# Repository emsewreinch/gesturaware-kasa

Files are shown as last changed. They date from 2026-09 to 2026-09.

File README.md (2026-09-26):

# gesturaware-kasa

GesturAware cihazinin 3D baski kasasi (OpenSCAD).

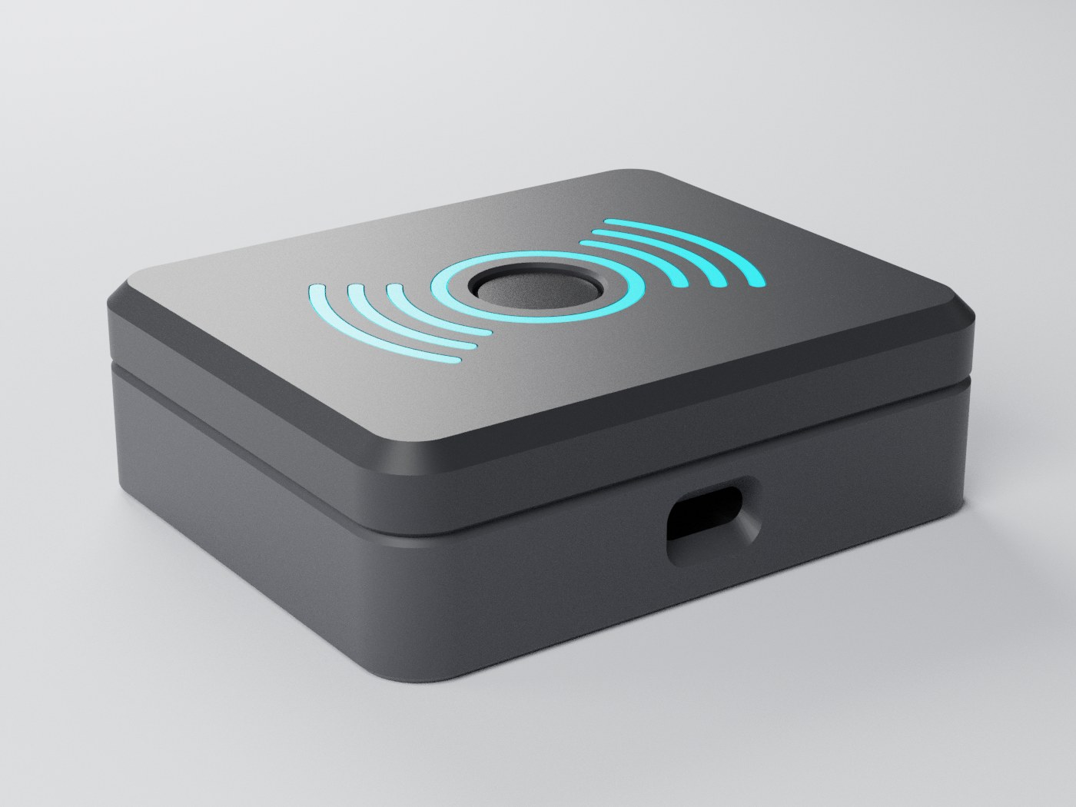
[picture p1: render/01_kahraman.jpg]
Kontrolcu surumu


## Dosyalar

- `kontrolcukasa.scad` - **kontrolcu surumu (yeni).** Oyun kontrolcusunun arkasina takilan 2 parcali kasa: kapak + govde. PCB v1 (`pcb_v1_headers_z.stl`) icin. `goster` degiskeni ile gorunum / parca secilir.
- `Cihazkasaguncel.scad` - masaustu surumu, iki parcali kasa (ust + alt), birlesik dosya. `goster` degiskeni ile gorunum secilir ("ust" / "alt" / "baski" / "acilim" / "montaj").
- `cihazkasaguncelust.scad` - masaustu ust kasa (tek parca, baski icin)
- `cihazkasaguncelalt.scad` - masaustu alt kapak (tek parca, baski icin)
- `cihaz_kasasi.scad`, `yenikasaa_ust.scad`, `yenikasaa_alt.scad` - onceki tasarim iterasyonlari
- `render/` - kontrolcu surumunun gorselleri

## Kontrolcu surumu (`kontrolcukasa.scad`)

Dis olculer degismedi: **64.74 x 53.5 x 20.6 mm**. Ic yapi PCB v1'e gore:
kart 45 x 40 x 1.6 mm, M2 delikler 39 x 34 mm aralikla, en yuksek komponent karttan 6.6 mm.
PCB, USB-C one bakacak sekilde 90 derece donuk durur; USB-C acikligi X = -0.4'te,
konnektorun kendi yuksekliginden hesaplanir (Z = 5.55 .. 8.95).

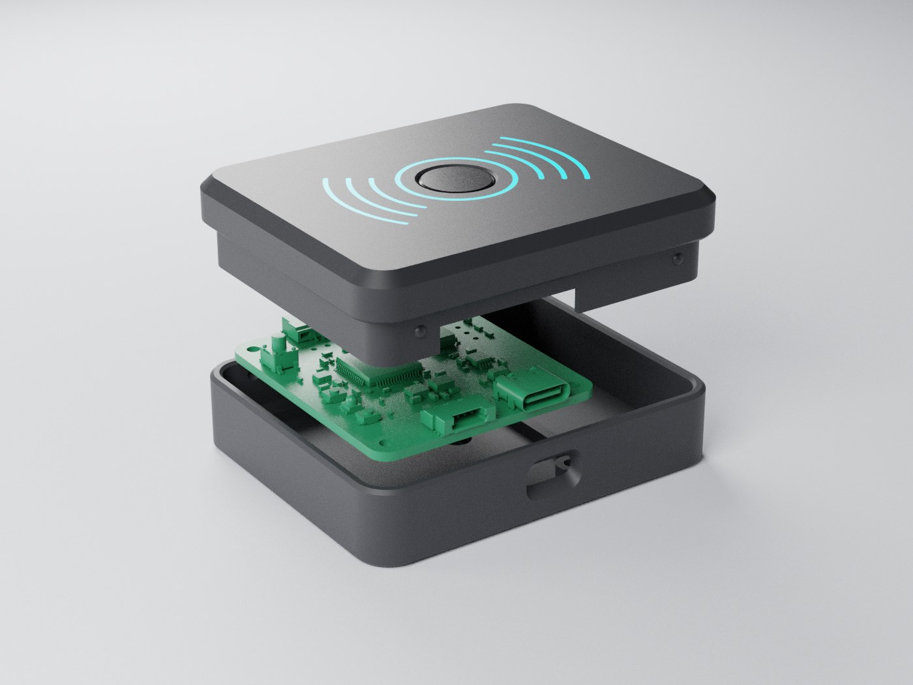
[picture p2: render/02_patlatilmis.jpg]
Parcalar


### Tasarim

- Duz ust yuzey, 45 derece pahli ust kenar (isikta keskin bir cizgi verir)
- Buton cevresinde hale halkasi ve iki yanda "(( o ))" jest dalgalari: 1.6 mm genis, 1.2 mm derin oyuk + renkli dolgu
- Kapak / govde birlesiminde 0.6 mm V-golge cizgisi; USB-C ve LED tamamen govdede, birlesim cizgisi portlari kesmiyor
- Plan kose radiusu 8 -> 6 mm: daha "tech" gorunum

| Ust yuzey | Beyaz kapak secenegi |
|---|---|
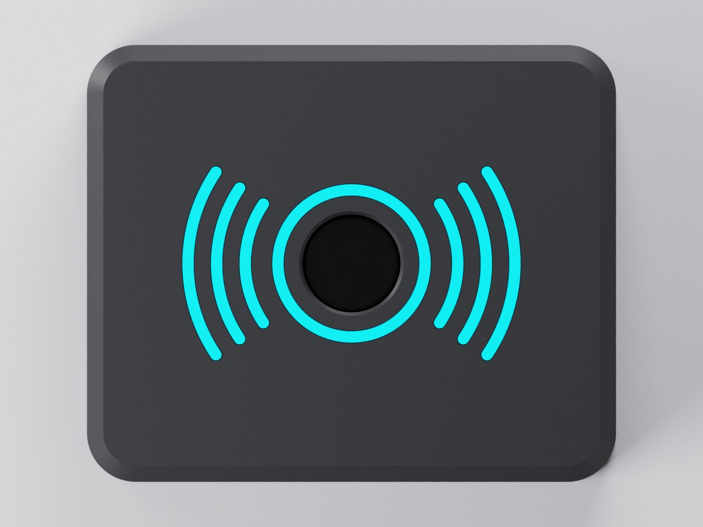
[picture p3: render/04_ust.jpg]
Ust
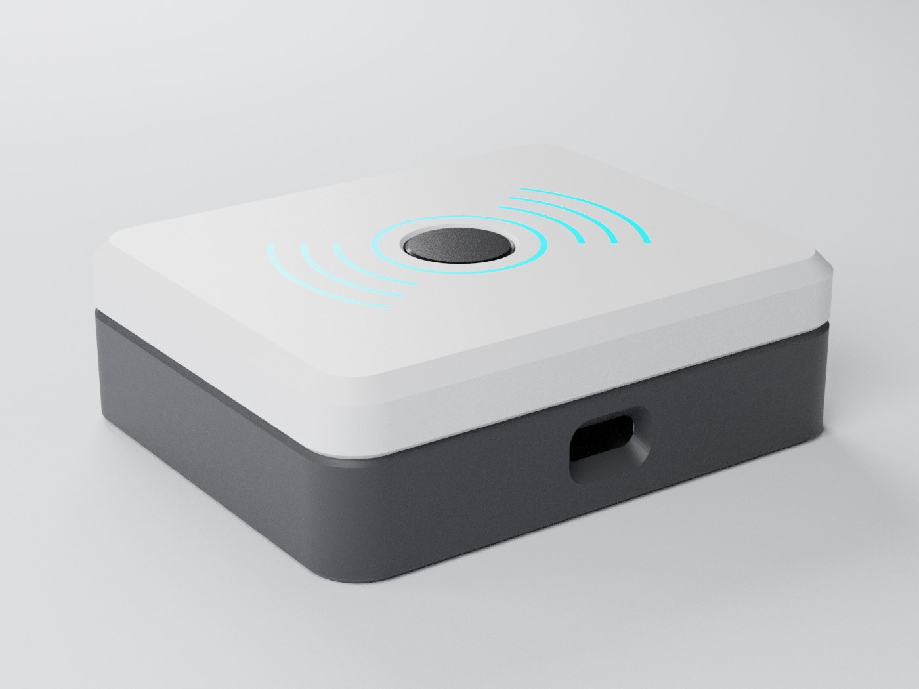
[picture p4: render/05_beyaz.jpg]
Beyaz
|  |  |

### Ic yapi ve PCB montaji

- PCB, delikleri altindaki 4 ayaga (2 mm) ve kenar rafina oturur.
- Tabanda PCB deliklerinin tam hizasinda havsali M2 delikler var: M2x8 havsa bas vida alttan,
  somun PCB ustunde. Vida basi taban yuzeyiyle ayni hizada kalir.
- Kapagin ic dudagi govdeye girer: 4 snap topu ile kilitlenir, 4 kucuk tirnakla PCB'yi
  yukaridan bastirir. Dudagin on tarafinda PCB'nin on kenarindan tasan USB-C ve konnektor icin centik var.
- PCB v1 modeli ile kontrol edildi: duvar, dudak ve tirnaklarla cakisma yok, ic duvara en az 0.47 mm pay.

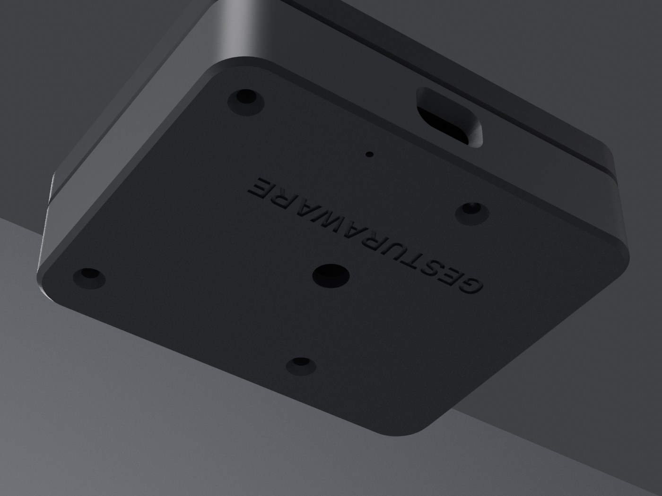
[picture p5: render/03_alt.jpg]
Alttan


### Baski (iki parca da desteksiz)

| Parca | STL icin `goster` | Tablaya gelen yuz | Not |
|---|---|---|---|
| Kapak | `kapak_baski` | ust yuzey | Dokulu PEI tabla premium mat doku verir |
| Govde | `govde_baski` | taban | |
| Dolgu | `inlay_baski` | duz | Vurgu renginde, oyuklara bastirilir |

```
openscad -D 'goster="kapak_baski"' -o kapak.stl kontrolcukasa.scad
openscad -D 'goster="govde_baski"' -o govde.stl kontrolcukasa.scad
openscad -D 'goster="inlay_baski"' -o inlay.stl kontrolcukasa.scad
```

**Renkli dolgu (inlay):** ust yuzeydeki halka ve dalgalar 1.6 mm genis, 1.2 mm derin oyuk (tavan 2.6 mm, oyuk altinda 1.4 mm kalir).
Renkli dolgu parcalari (`inlay_baski`, 7 parca) ayri basilir ve oyuklara bastirilir: her kenardan
0.14 mm kucuk (`inlay_bosluk`, 0.12 - 0.16 arasi ayarlanabilir): 1.32 mm genis (0.4 nozulla 3 cizgi), 1.2 mm yuksek.
Gerekirse bir damla yapistiriciyla sabitle.

### Montaj sirasi

1. PCB'yi govdeye yerlestir (USB-C one), 4 M2x8 havsa bas vidayi alttan tak, somunlari PCB ustunden sik.
2. LED'i arka duvardaki 5 mm delige icten tak.
3. Kapagi bastir: dudak govdeye girer, snap'ler klik yapar.

### Ayarlar

| Degisken | Varsayilan | Ne yapar |
|---|---|---|
| `usb_cx`, `pcb_cy` | -0.4, -0.7 | PCB konumu (USB-C acikligi ve vida delikleri birlikte kayar) |
| `vida_d`, `havsa_d` | 2.4, 4.4 | M2 gecis deligi ve havsa capi |
| `snap_int` | 0.4 | Kapak kilit sertligi |
| `tirnak_x` | montaj delikleri yani | PCB bastirma tirnaklari; gerekirse `tirnak_on = false` |
| `inlay_bosluk` | 0.14 | Dolgu parcasi her kenardan bu kadar kucuk |
| `oyma_on`, `yazi_on` | true | Ust desen / alt yazi |
| `pcb_goster` | false | Montaj gorunumlerinde PCB hayaleti |

## Masaustu surumu (`Cihazkasaguncel.scad`)

- Apple / minimalist tarz, duz ust yuzey
- Ortada 12 mm buton deligi
- On (-Y) duvarda USB-C acikligi (merkeze gore 1 mm saga kaydirilmis)
- Vidasiz snap kenetlenme: alt kapak lip'i uzerinde detent toplari, ust kasa ic duvarinda eslesen yuvalar. Sikilik `snap_int` ile ayarlanir.

## Kullanim

OpenSCAD ile ac, F5 onizleme / F6 render, sonra STL disa aktar (F7).

Dis olculer: ~64.7 x 53.5 x 20.6 mm.

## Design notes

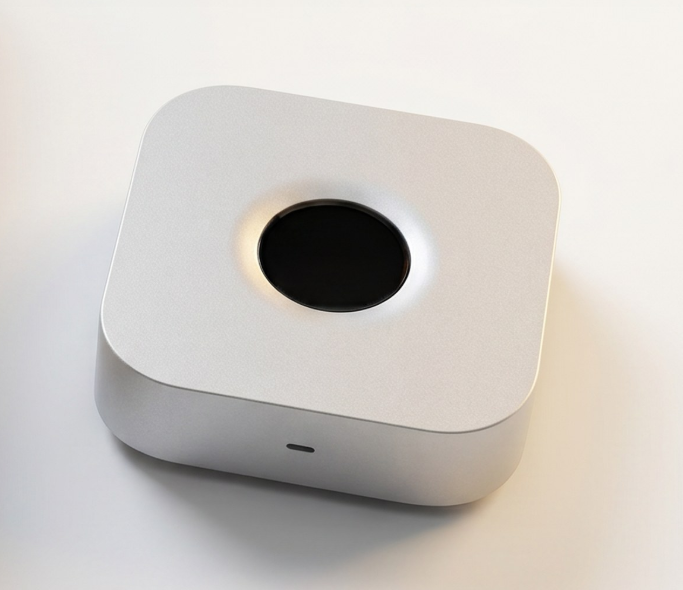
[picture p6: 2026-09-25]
Ekran görüntüsü 2026-09-13 182629.png

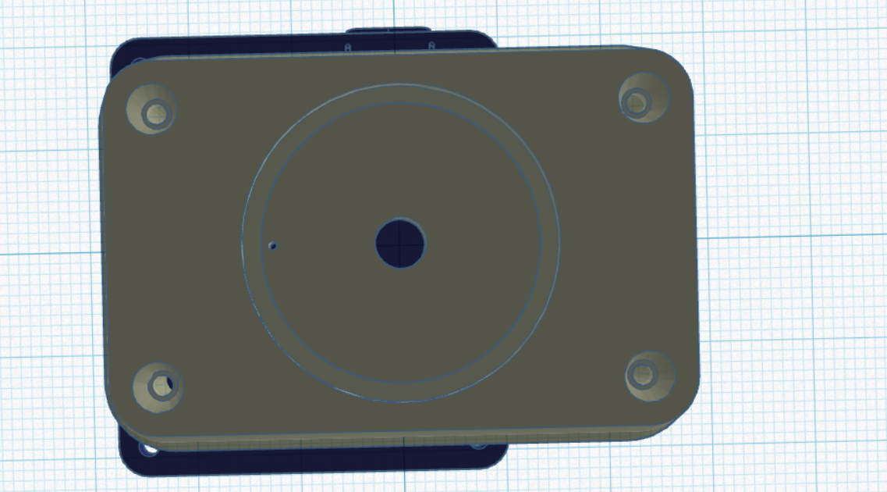
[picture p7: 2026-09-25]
yenikasaproblem1.png

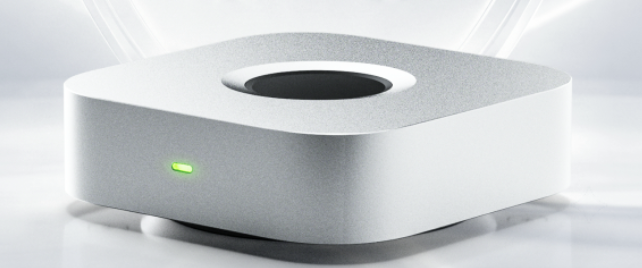
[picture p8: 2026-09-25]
Ekran görüntüsü 2026-09-13 183102.png

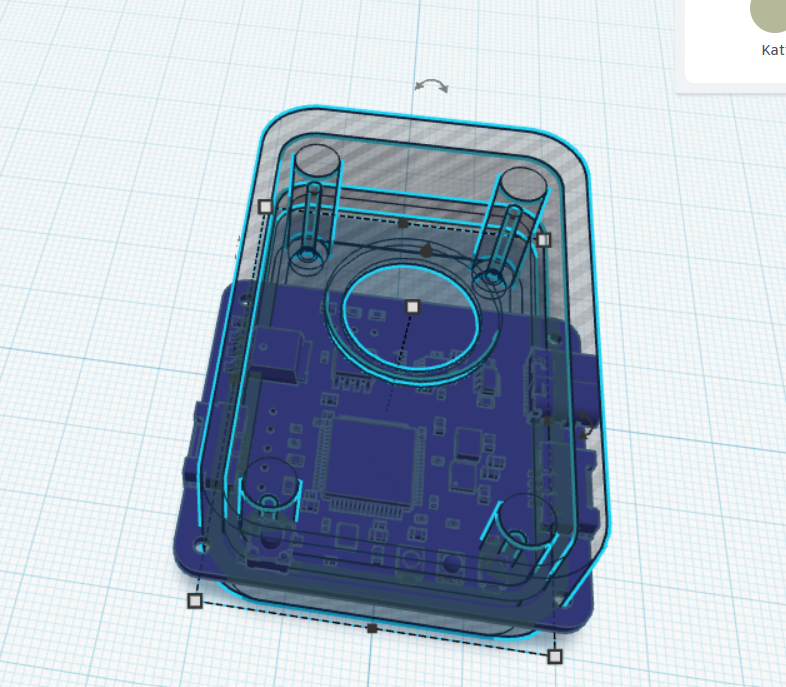
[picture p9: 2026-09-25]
yenikasaproblem2.png

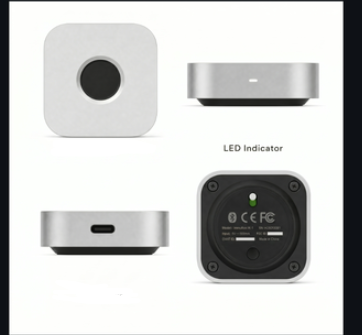
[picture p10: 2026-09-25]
Ekran görüntüsü 2026-09-13 184225.png

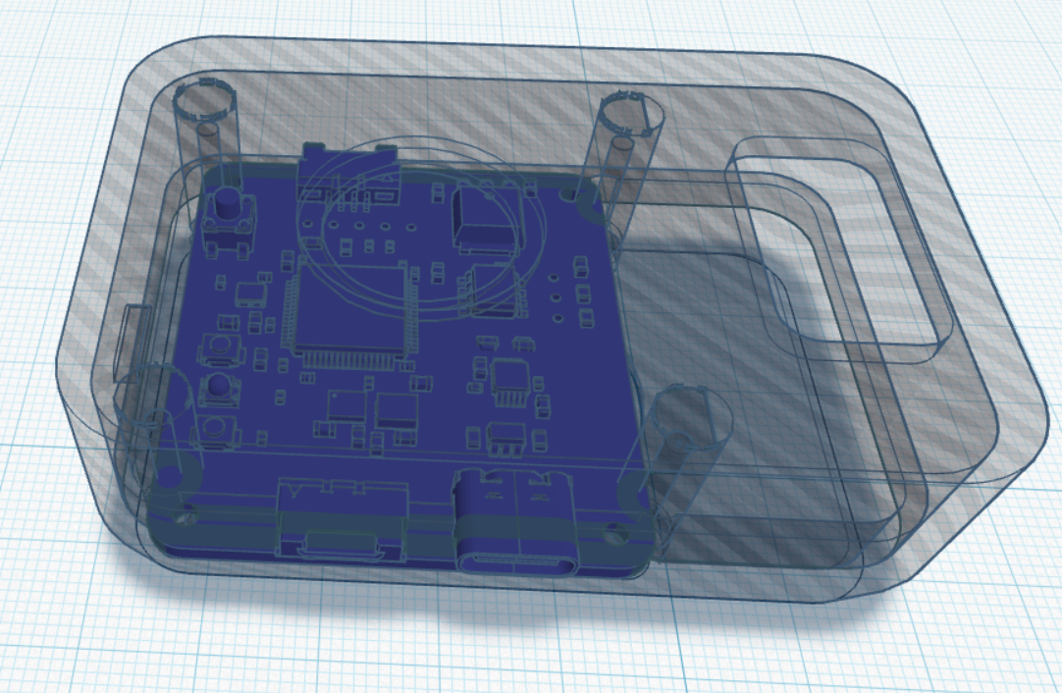
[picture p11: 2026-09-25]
yenikasaistek.png

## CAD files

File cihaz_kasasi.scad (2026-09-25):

// =============================================================
//  Cihaz Kasasi - iki parcali (ust kasa + alt kapak)  v4
//  Apple/minimalist. USB-C UZUN (on) duvarda TAM ORTADA.
//
//  Yerlesim (ustten):
//    [ PCB (EN SOLDA) ] [ gap ] [ LED (sagda) ]
//  Kart, USB kenari one bakacak sekilde; kart SOLA dayanir,
//  konnektor tam kasa merkezine gelir -> USB acikligi ortada,
//  gercek konnektorle HIZALI. Sag tarafta LED icin bosluk kalir.
//
//  KRITIK: usb_edge_off = konnektorun kart on-kenari merkezinden
//  ic tarafa (saga) kacikligi. kapaklar.scad'den 8.62 alindi.
//  Gercek kartta farkliysa TEK burayi degistir; kasa kendini ayarlar.
//
//  Tum olculer mm. z=0 tabanin en alti.
// =============================================================

$fn = 100;

/* ============================================================
   =  BILESENLER (olculen)                                     =
   ============================================================ */
pcb_edge_usb = 40.5;   // kartin USB kenari boyu -> kasa X
pcb_depth    = 46.5;   // kartin diger boyutu    -> kasa Y (en/derinlik)
pcb_thick    = 1.6;
pcb_comp_h   = 10;     // kart ustu en yuksek komponent payi
hole_ax      = 17;     // montaj deligi yari-araligi (kasa X)
hole_ay      = 19.5;   // montaj deligi yari-araligi (kasa Y)

usb_edge_off = 8.62;   // <-- konnektor, kart on-kenari merkezinden saga kacik (kapaklar.scad)
usb_w        = 9.2;    // Type-C acikligi X (uzun duvar boyunca)
usb_h        = 3.4;    // Type-C acikligi Z (yukseklik)
usb_dz       = 1.2;    // konnektor merkezinin kart USTUNDEN yuksekligi

led_ekle     = true;   // sagdaki bosluga LED modulu (hayalet + yer)
led_X        = 15;
led_Y        = 25;
led_h        = 16;

/* ============================================================
   =  YERLESIM / BOSLUKLAR                                     =
   ============================================================ */
side_clr   = 1.5;
comp_gap   = 2.0;
head_gap   = 3.0;
floor_gap  = 2.0;

/* ============================================================
   =  ESTETIK / KASA                                           =
   ============================================================ */
et            = 2;
kose_r        = 8;
taban_yuks    = 7;
lip_yuks      = 4;
lip_bosluk    = 0.3;
lip_et        = 1.5;
chamfer_inset = 2.5;

buton_cap     = 16;    // ustteki basilabilir buton deligi
havuz_cap     = 20;
havuz_derin   = 1.2;
buton_x       = 0;     // buton konumu: 0 = UST YUZEYIN TAM ORTASI (X=0 halen PCB uzerinde)
buton_y       = 0;

sutun_cap     = 5.5;
boss_cap      = 6.0;
vida_ic_cap   = 2.2;
pilot_derin   = 12;
kapak_delik   = 2.8;
havsa_ust_cap = 5.0;
havsa_derin   = 2.2;

sensor_cap    = 5.0;
reset_cap     = 1.0;
lastik_r_dis  = 15;
lastik_r_ic   = 13;
lastik_derin  = 1.0;

/* ============================================================
   =  TURETILEN OLCULER + KONUMLAR                             =
   ============================================================ */
usb_cx = 0;                 // USB acikligi tam ortada
bd_cx  = -usb_edge_off;     // kart merkezi -> konnektor X=0'a gelsin (kart sola kayar)
bd_cy  = 0;

board_l = bd_cx - pcb_edge_usb/2;   // kart sol kenari (en solda)
board_r = bd_cx + pcb_edge_usb/2;   // kart sag kenari

led_l  = board_r + comp_gap;        // LED sag bosluga
led_cx = led_l + led_X/2;
led_r  = led_l + led_X;

// Kabuk X=0 etrafinda SIMETRIK -> USB tam ortada, sol bosluk yok
right_ext = led_ekle ? max(board_r, led_r) : board_r;
half_in   = max(-board_l, right_ext) + side_clr;   // ic kavite yari-X
uzunluk   = 2*(half_in + et);                      // X (dis)

inner_y  = pcb_depth + 2*side_clr;
genislik = inner_y + 2*et;                          // Y (dis)
inner_h  = max(led_h, floor_gap + pcb_thick + pcb_comp_h) + head_gap;
toplam_yuks = inner_h + 2*et;

z_floor_top = et;
z_rest      = z_floor_top + floor_gap;
z_pcb_top   = z_rest + pcb_thick;
tavan_z     = toplam_yuks - et;
seam_z      = taban_yuks;
usb_cz      = z_pcb_top + usb_dz;

cc = 0;   // kabuk merkezi (simetrik)

hole_positions = [ for (sx=[-1,1], sy=[-1,1]) [bd_cx + sx*hole_ax, sy*hole_ay] ];

/* =============================================================
                     YARDIMCI MODULLER
   ============================================================= */
module rrect(l, w, r) {
    rr = max(min(r, l/2, w/2), 0.1);
    hull() for (sx = [-1, 1], sy = [-1, 1])
        translate([sx*(l/2 - rr), sy*(w/2 - rr)]) circle(r = rr);
}
module rbox(l, w, h, r) { linear_extrude(height = h) rrect(l, w, r); }

/* =============================================================
                        UST KASA
   ============================================================= */
module ust_kasa() {
    union() {
        difference() {
            translate([cc, 0, seam_z])
                rbox(uzunluk, genislik, toplam_yuks - seam_z, kose_r);
            translate([cc, 0, seam_z - 1])
                rbox(uzunluk - 2*et, genislik - 2*et,
                     tavan_z - (seam_z - 1), kose_r - et);
            buton_bosluk();     // PCB merkezi uzerinde
            usb_bosluk();       // on (-Y) uzun duvar, tam ortada
        }
        ust_standoffs();
    }
}

module buton_bosluk() {
    translate([buton_x, buton_y, toplam_yuks - havuz_derin])
        cylinder(h = havuz_derin + 0.1, d = havuz_cap);
    translate([buton_x, buton_y, tavan_z - 0.1])
        cylinder(h = et + 0.2, d = buton_cap);
}

// USB kesimi: -Y (on) duvarda, X=usb_cx (orta), stadyum slot
module usb_bosluk() {
    r = usb_h / 2;
    translate([usb_cx, -genislik/2, usb_cz])
        hull()
            for (dx = [-(usb_w/2 - r), (usb_w/2 - r)])
                translate([dx, 0, 0])
                    rotate([90, 0, 0])
                        cylinder(h = et + 4, r = r, center = true, $fn = 48);
}

module ust_standoffs() {
    for (p = hole_positions)
        translate([p[0], p[1], z_pcb_top])
            difference() {
                cylinder(h = tavan_z - z_pcb_top, d = sutun_cap);
                translate([0, 0, -0.1]) cylinder(h = pilot_derin, d = vida_ic_cap);
            }
}

/* =============================================================
                        ALT KAPAK
   ============================================================= */
module alt_kapak() {
    difference() {
        union() {
            difference() { etek_solid(); skirt_ic(); }
            lip();
            alt_bosslar();
        }
        kapak_vida_delikleri();
        usb_bosluk();   // USB seam'i asar -> alt kabukta da acilir
        translate([cc, 0, -1]) cylinder(h = et + 2, d = sensor_cap);
        translate([bd_cx, -hole_ay - 2, -1]) cylinder(h = et + 2, d = reset_cap);
        lastik_olugu();
    }
}

module etek_solid() {
    translate([cc, 0, 0]) hull() {
        linear_extrude(height = 0.1)
            rrect(uzunluk - 2*chamfer_inset, genislik - 2*chamfer_inset,
                  kose_r - chamfer_inset);
        translate([0, 0, seam_z - 0.1])
            linear_extrude(height = 0.1) rrect(uzunluk, genislik, kose_r);
    }
}
module skirt_ic() {
    translate([cc, 0, 0]) hull() {
        translate([0, 0, et]) linear_extrude(height = 0.1)
            rrect(uzunluk - 2*chamfer_inset - 2*et,
                  genislik - 2*chamfer_inset - 2*et,
                  max(kose_r - chamfer_inset - et, 0.5));
        translate([0, 0, seam_z]) linear_extrude(height = 0.1)
            rrect(uzunluk - 2*et, genislik - 2*et, kose_r - et);
    }
}
module lip() {
    translate([cc, 0, et]) linear_extrude(height = (seam_z - et) + lip_yuks)
        difference() {
            rrect(uzunluk - 2*et - 2*lip_bosluk, genislik - 2*et - 2*lip_bosluk,
                  kose_r - et - lip_bosluk);
            rrect(uzunluk - 2*et - 2*lip_bosluk - 2*lip_et,
                  genislik - 2*et - 2*lip_bosluk - 2*lip_et,
                  max(kose_r - et - lip_bosluk - lip_et, 0.5));
        }
}
module alt_bosslar() {
    for (p = hole_positions)
        translate([p[0], p[1], et]) cylinder(h = z_rest - et, d = boss_cap);
}
module kapak_vida_delikleri() {
    for (p = hole_positions)
        translate([p[0], p[1], 0]) {
            translate([0, 0, -0.1]) cylinder(h = z_rest + 1, d = kapak_delik);
            translate([0, 0, -0.1])
                cylinder(h = havsa_derin + 0.1, d1 = havsa_ust_cap, d2 = kapak_delik);
        }
}
module lastik_olugu() {
    translate([cc, 0, -0.01]) linear_extrude(height = lastik_derin + 0.01)
        difference() { circle(r = lastik_r_dis); circle(r = lastik_r_ic); }
}
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

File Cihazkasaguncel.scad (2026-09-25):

// =============================================================
// Cihaz Kasasi - iki parcali
// Ust kasa + alt kapak
// Apple / minimalist
// USB-C on (-Y) duvarda TAM ORTADA
//
// Tum olculer mm.
// Z=0 tabanin en alti.
// =============================================================

$fn = 100;


// =============================================================
// BILESEN / PCB OLCULERI
// =============================================================

pcb_edge_usb = 40.5;       // PCB X boyu
pcb_depth    = 46.5;       // PCB Y boyu
pcb_thick    = 1.6;

pcb_comp_h   = 10;         // PCB ustu maksimum komponent yuksekligi

hole_ax = 17;              // Vida delikleri X yari-araligi
hole_ay = 19.5;            // Vida delikleri Y yari-araligi

// USB konnektorunun PCB on kenarindan iceri kacikligi
usb_edge_off = 8.62;

usb_w     = 9.2;           // USB-C acikligi X (evrensel ~9.0-9.2mm)
usb_bos_h = 3.4;           // USB-C acikligi Z (evrensel ~3.2-3.4mm)
usb_alt   = 4;             // acikligin alt kenari tabandan yukseklik (4mm)
usb_r     = 1.7;           // kose yuvarlatma (uclar tam yuvarlak = kapsul)

// On agiz: kablonun GOVDESI (apple type-c) de rahatca otursun diye on yuzde flare
usb_agiz_w     = 10.5;     // on agiz genisligi (apple kablo govde genisligi gibi)
usb_agiz_h     = 7.0;      // on agiz yuksekligi
usb_agiz_r     = 2.5;      // on agiz kose yuvarlatma
usb_agiz_derin = 2;        // flare derinligi (et=2 => tum on katman chamfer)


// =============================================================
// YERLESIM / BOSLUKLAR
// =============================================================

side_clr  = 1.5;           // PCB-kasa yan boslugu
head_gap  = 3.0;           // PCB ustu bosluk
floor_gap = 2.0;           // PCB alt boslugu


// =============================================================
// KASA AYARLARI
// =============================================================

et = 2;                    // Duvar kalinligi

kose_r = 8;                // Dis koselerin radiusu

taban_yuks = 7;            // Alt kapak / seam yuksekligi

lip_yuks  = 4;
lip_bosluk = 0.3;
lip_et = 1.5;

chamfer_inset = 2.5;


// =============================================================
// SNAP - VIDASIZ KENETLENME
// Lip uzerindeki detent toplari, ust kasadaki yuvalara oturur.
// =============================================================

snap_on       = true;   // snap kenetlenme acik/kapali
snap_x_off    = 20;     // snap'lerin merkezden X uzakligi (USB'yi es gecer)
snap_d        = 2.4;    // lip uzerindeki detent topu capi
snap_pocket_d = 2.9;    // ust duvardaki yuva capi (bumptan buyuk)
snap_int      = 0.4;    // sikilik / interferans (mm) - artir = daha sert klik


// =============================================================
// UST BUTON
// =============================================================

buton_cap = 12;
havuz_cap = 20;
havuz_derin = 1.2;

buton_x = 0;
buton_y = 0;

// Ust tumsek (buton meme-ucu gibi durmasin diye)
tepe_h     = 3.5;          // buton cevresi tumsek merkez yuksekligi (duz uste gore)
tepe_r     = 22;           // bu yaricapta duz uste tegetlenir (tumsek yaricapi)
tepe_steps = 48;           // profil cozunurlugu


// =============================================================
// VIDA / MONTAJ
// =============================================================

sutun_cap = 5.5;
boss_cap = 6.0;

vida_ic_cap = 2.2;
pilot_derin = 12;

kapak_delik = 2.8;

havsa_ust_cap = 5.0;
havsa_derin = 2.2;


// =============================================================
// ALT SENSOR / RESET DELIKLERI
// =============================================================

sensor_cap = 5.0;
reset_cap = 1.0;


// =============================================================
// ALT KAPAK LASTIK OLGUSU
// =============================================================

lastik_r_dis = 15;
lastik_r_ic = 13;
lastik_derin = 1.0;


// =============================================================
// ARKA SEFFAF NOKTA (tek-katman isik gecisi)
// =============================================================

nokta_cap   = 1.0;         // nokta capi
nokta_kalan = 0.4;         // ic yuzeyde kalan et (~2 katman; 0.2 = tek katman)
nokta_x     = 0;           // arka (+Y) duvarda X konumu


// =============================================================
// ARKA LED DELIGI (5mm LED - arka +Y duvar, sag)
// =============================================================

led_cap = 5.0;             // 5mm LED icin delik capi
led_x   = 18;              // +X (sag) konum
led_z   = 10;              // yukseklik (tabandan)


// =============================================================
// TURETILEN OLCULER
// =============================================================

// USB-C merkeze gore 1 mm saga (+X) kaydirildi
usb_cx = 1;

// PCB, USB konnektorunu kasa merkezine getirmek icin sola kayiyor
bd_cx = -usb_edge_off;

bd_cy = 0;


// PCB X sinirlari
board_l = bd_cx - pcb_edge_usb / 2;
board_r = bd_cx + pcb_edge_usb / 2;


// PCB'nin en dis noktasi + bosluk
right_ext = board_r;

half_in = max(-board_l, right_ext) + side_clr;


// =============================================================
// KASA DIS X BOYUTU
// =============================================================

uzunluk = 2 * (half_in + et);


// =============================================================
// KASA DIS Y BOYUTU
// =============================================================

inner_y = pcb_depth + 2 * side_clr;

genislik = inner_y + 2 * et;


// =============================================================
// KASA Z BOYUTU
// =============================================================

inner_h =
    floor_gap
    + pcb_thick
    + pcb_comp_h
    + head_gap;

toplam_yuks = inner_h + 2 * et;


// Alt ic taban
z_floor_top = et;

// PCB alt seviyesi
z_rest = z_floor_top + floor_gap;

// PCB ust seviyesi
z_pcb_top = z_rest + pcb_thick;

// Ust tavanin ic yuzeyi
tavan_z = toplam_yuks - et;

// Ust / alt kapak birlesim seviyesi
seam_z = taban_yuks;

// Arka seffaf nokta yuksekligi (seam ile tavan arasi orta)
nokta_z = (seam_z + tavan_z) / 2;


// USB acikligi dikey sinirlari (alt kenar tabandan usb_alt, yukseklik usb_bos_h)
usb_z0 = usb_alt;
usb_z1 = usb_alt + usb_bos_h;


// Kasa merkezi
cc = 0;


// =============================================================
// VIDA DELIK POZISYONLARI
// =============================================================

hole_positions =
[
    for (sx = [-1, 1], sy = [-1, 1])
    [
        bd_cx + sx * hole_ax,
        sy * hole_ay
    ]
];


// =============================================================
// YARDIMCI MODULLER
// =============================================================

module rrect(l, w, r)
{
    rr = max(min(r, l / 2, w / 2), 0.1);

    hull()
    {
        for (sx = [-1, 1], sy = [-1, 1])
        {
            translate(
                [
                    sx * (l / 2 - rr),
                    sy * (w / 2 - rr)
                ]
            )
            circle(r = rr);
        }
    }
}


module rbox(l, w, h, r)
{
    linear_extrude(height = h)
        rrect(l, w, r);
}


// =============================================================
// UST KASA
// =============================================================

module ust_kasa()
{
    union()
    {
        difference()
        {
            // -------------------------------------------------
            // DIS KABUK + UST TUMSEK
            // -------------------------------------------------

            union()
            {
                translate(
                    [
                        cc,
                        0,
                        seam_z
                    ]
                )
                rbox(
                    uzunluk,
                    genislik,
                    toplam_yuks - seam_z,
                    kose_r
                );

                // ust_tepe();   // UST TUMSEK KALDIRILDI - duz ust istendi
            }


            // -------------------------------------------------
            // IC BOSLUK
            // -------------------------------------------------

            translate(
                [
                    cc,
                    0,
                    seam_z - 1
                ]
            )
            rbox(
                uzunluk - 2 * et,
                genislik - 2 * et,
                tavan_z - (seam_z - 1),
                kose_r - et
            );


            // -------------------------------------------------
            // UST BUTON BOSLUGU
            // -------------------------------------------------

            buton_bosluk();


            // -------------------------------------------------
            // USB-C BOSLUGU
            // -------------------------------------------------

            usb_bosluk();
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

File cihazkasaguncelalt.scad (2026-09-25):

// =============================================================
// GESTURAWARE - ALT KAPAK
// Tek parca alt kapak
// Apple / minimalist
//
// Tum olculer mm.
// Z=0 tabanin en alti
// =============================================================

$fn = 100;


// =============================================================
// PCB OLCULERI
// =============================================================

pcb_edge_usb = 40.5;
pcb_depth    = 46.5;

side_clr = 1.5;

et = 2;
kose_r = 8;

taban_yuks = 7;


// =============================================================
// USB-C
// =============================================================

usb_edge_off = 8.62;

usb_w     = 9.2;
usb_bos_h = 3.4;
usb_alt   = 4;
usb_r     = 1.7;

usb_agiz_w     = 10.5;
usb_agiz_h     = 7.0;
usb_agiz_r     = 2.5;
usb_agiz_derin = 2;


// =============================================================
// VIDA / MONTAJ
// =============================================================

hole_ax = 17;
hole_ay = 19.5;

kapak_delik = 2.8;

havsa_ust_cap = 5.0;
havsa_derin   = 2.2;


// =============================================================
// ALT DELIKLER
// =============================================================

sensor_cap = 5.0;
reset_cap  = 1.0;


// =============================================================
// ALT KAPAK LASTIK OLGUSU
// =============================================================

lastik_r_dis = 15;
lastik_r_ic  = 13;
lastik_derin = 1.0;


// =============================================================
// KASA AYARLARI
// =============================================================

lip_yuks   = 4;
lip_bosluk = 0.3;
lip_et     = 1.5;

chamfer_inset = 2.5;


// =============================================================
// SNAP - VIDASIZ KENETLENME
// Lip uzerindeki detent toplari, ust kasadaki yuvalara oturur.
// =============================================================

snap_on       = true;   // snap kenetlenme acik/kapali
snap_x_off    = 20;     // snap'lerin merkezden X uzakligi (USB'yi es gecer)
snap_d        = 2.4;    // lip uzerindeki detent topu capi
snap_pocket_d = 2.9;    // ust duvardaki yuva capi (bumptan buyuk)
snap_int      = 0.4;    // sikilik / interferans (mm) - artir = daha sert klik


// =============================================================
// TURETILEN OLCULER
// =============================================================

// PCB merkezi
bd_cx = -usb_edge_off;


// PCB X sinirlari
board_l = bd_cx - pcb_edge_usb / 2;
board_r = bd_cx + pcb_edge_usb / 2;


// PCB + yan bosluk
right_ext = board_r;

half_in = max(-board_l, right_ext) + side_clr;


// Kasa dis X
uzunluk = 2 * (half_in + et);


// Kasa dis Y
inner_y = pcb_depth + 2 * side_clr;
genislik = inner_y + 2 * et;


// Birlesim seviyesi
seam_z = taban_yuks;


// =============================================================
// VIDA POZISYONLARI
// =============================================================

hole_positions =
[
    for (sx = [-1, 1], sy = [-1, 1])
    [
        bd_cx + sx * hole_ax,
        sy * hole_ay
    ]
];


// =============================================================
// YARDIMCI MODUL
// =============================================================

module rrect(l, w, r)
{
    rr = max(min(r, l / 2, w / 2), 0.1);

    hull()
    {
        for (sx = [-1, 1], sy = [-1, 1])
        {
            translate(
                [
                    sx * (l / 2 - rr),
                    sy * (w / 2 - rr)
                ]
            )
            circle(r = rr);
        }
    }
}


// =============================================================
// ALT KAPAK
// =============================================================

module alt_kapak()
{
    difference()
    {
        union()
        {
            // Ana govde
            difference()
            {
                etek_solid();
                skirt_ic();
            }

            // Ic gecme lip'i
            lip();

            // Vidasiz snap toplari
            snap_bumps();
        }


        // -----------------------------------------------------
        // VIDA DELIKLERI
        // -----------------------------------------------------

        kapak_vida_delikleri();


        // -----------------------------------------------------
        // USB-C DELIGI
        // -----------------------------------------------------

        usb_bosluk();


        // -----------------------------------------------------
        // SENSOR DELIGI
        // -----------------------------------------------------

        translate(
            [
                0,
                0,
                -1
            ]
        )
        cylinder(
            h = et + 2,
            d = sensor_cap
        );


        // -----------------------------------------------------
        // RESET DELIGI
        // -----------------------------------------------------

        translate(
            [
                bd_cx,
                -hole_ay - 2,
                -1
            ]
        )
        cylinder(
            h = et + 2,
            d = reset_cap
        );


        // -----------------------------------------------------
        // LASTIK OLGUSU
        // -----------------------------------------------------

        lastik_olugu();
    }
}


// =============================================================
// ALT KAPAK DIS GOVDESI
// =============================================================

module etek_solid()
{
    translate([0, 0, 0])
    hull()
    {
        // Alt kisim
        linear_extrude(height = 0.1)
        rrect(
            uzunluk - 2 * chamfer_inset,
            genislik - 2 * chamfer_inset,
            kose_r - chamfer_inset
        );


        // Ust kisim
        translate(
            [
                0,
                0,
                seam_z - 0.1
            ]
        )
        linear_extrude(height = 0.1)
        rrect(
            uzunluk,
            genislik,
            kose_r
        );
    }
}


// =============================================================
// ALT KAPAK IC BOSLUGU
// =============================================================

module skirt_ic()
{
    translate([0, 0, 0])
    hull()
    {
        // Alt ic kisim
        translate(
            [
                0,
                0,
                et
            ]
        )
        linear_extrude(height = 0.1)
        rrect(
            uzunluk
                - 2 * chamfer_inset
                - 2 * et,

            genislik
                - 2 * chamfer_inset
                - 2 * et,
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

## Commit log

2026-09-25 GesturAware kasa: OpenSCAD kaynak dosyalari ve gorseller
    Duz ust yuzey, 12mm buton deligi, USB-C 1mm saga kaydirildi,
    vidasiz snap kenetlenme sistemi (lip detent + ust yuva).
    [Cihazkasaguncel.scad, cihaz_kasasi.scad, cihazkasaguncelalt.scad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]
2026-09-25 Kontrolcu surumu: kizakli premium kasa (kontrolcukasa.scad)
    - Dis olculer ayni (64.74 x 53.5 x 20.6 mm); PCB, USB-C, buton, LED,
    sensor ve reset konumlari Cihazkasaguncel.scad ile ayni
    - 3 parca (kapak, govde, kizak), hepsi desteksiz basilir
    - 45 derece ust pah, buton cevresinde hale halkasi ve "(( o ))" jest
    dalgalari (0.4 mm oyma, renkli baski / inlay destegi), V-golge cizgileri
    - Kontrolcuye VHB bantla yapisan kizak: kirlangic ray, arka durdurucu,
    esnek parmakli klik kilit, tikirti alan taban tumsekleri
    - PCB rafi ve kapak tirnaklari; dudak ile PCB kenari arasinda 0.3 mm pay
    (eski dosyada dudak PCB kenarina ~0.3 mm giriyordu)
    - README guncellendi, render gorselleri eklendi
    Co-Aut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
    [kontrolcukasa.scad]
2026-09-26 USB-C acikligini 1.4 mm sola, 0.5 mm asagi kaydir
    usb_cx 1 -> -0.4, usb_alt 4 -> 3.5. Dudak centigi ve raf boslugu
    otomatik takip ediyor; render gorselleri guncellendi.
    Claude-Session: https://claude.ai/code/session_01Cw47JAQLn6ddWJcZ3qnMbE
    [kontrolcukasa.scad]
2026-09-26 Kizagi kaldir, kasayi PCB v1'e gore guncelle
    - Kizak (dovetail ray, esnek parmaklar) ve govdedeki kizak oluklari kaldirildi;
    govde tabani her yonde pahli duz taban
    - PCB olculeri pcb_v1_headers_z.stl'den: 45 x 40 x 1.6 mm, M2 delikler
    39 x 34 mm, komponent yuksekligi 6.6 mm; dis olculer sabit
    - Tabanda PCB deliklerinin hizasinda havsali M2 delikler ve 2 mm PCB ayaklari
    - USB-C acikligi konnektorun modeldeki yuksekliginden hesaplaniyor
    - Dudak on centigi PCB on kenarindan tasan konnektorlere gore genisletildi,
    on snap'ler centik disina alindi
    - README ve render gorselleri guncellendi
    Claude-Session: https://claude.ai/code/session_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
    [kontrolcukasa.scad]
2026-09-26 Ust desen: 1.6 x 1.2 mm oyuk ve ayri basilan dolgu parcalari
    - Halka ve dalga oyuklari 0.8 -> 1.6 mm genis, 0.4 -> 1.2 mm derin
    - Kapak tavani 2.0 -> 2.6 mm; oyuk altinda 1.4 mm kalir
    - inlay_baski: oyuktan her kenardan 0.14 mm kucuk (inlay_bosluk),
    1.32 mm genis (0.4 nozulla 3 cizgi), 1.2 mm yuksek dolgu parcalari
    - Alt yazi derinligi ayri parametre (0.4 mm)
    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
    [kontrolcukasa.scad]
